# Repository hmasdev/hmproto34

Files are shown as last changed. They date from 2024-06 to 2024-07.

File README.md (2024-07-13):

# hmproto34







hmproto34 is a hand-fitted keyboard with 34 keys.

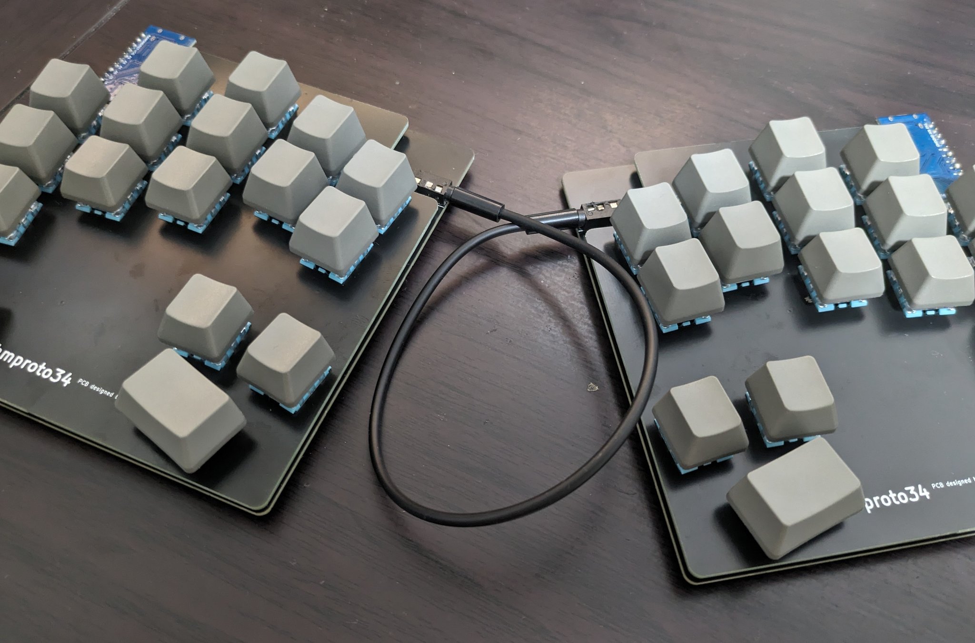
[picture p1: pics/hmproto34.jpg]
hmproto34


## How to Use Firmware

The most simple way to use hmproto34 is to flash the pre-built firmware to your keyboard.

Download the latest firmware from [Releases](https://github.com/hmasdev/hmproto34/releases) and follow the instructions in [How to Flash Firmware](#how-to-flash-firmware).

The next 2 subsections explain how to build firmware and flash it to your keyboard.

If you want to know how to build the keyboard, see [How to Build Keyboard](#how-to-build-keyboard).

### How to Build Firmware

1. Setup your QMK environment
   - if you use Windows, install [QMK MSYS](https://msys.qmk.fm/)
   - See [https://docs.qmk.fm/#/newbs_getting_started?id=set-up-your-environment](https://docs.qmk.fm/#/newbs_getting_started?id=set-up-your-environment) for more information.
   - NOTE: assume that `qmk_firmware` directory is located at `~/qmk_firmware` in the following steps.

2. Open QMK MSYS
   - If you use Windows, open QMK from the start menu. See [https://msys.qmk.fm/guide.html#next-steps](https://msys.qmk.fm/guide.html#next-steps).

3. Clone this repository

   ```sh
   cd ~/qmk_firmware/keyboards
   git clone git@github.com:hmasdev/hmproto34.git
   ```

4. Build firmware

   ```sh
   qmk compile -kb hmproto34 -km default
   ```

Good! Now, you have a built firmware in `~/qmk_firmware/.build/hmproto34_default.hex`.

### How to Flash Firmware

1. Visit [Pro Micro Web Updater](https://sekigon-gonnoc.github.io/promicro-web-updater/index.html);
2. Select the firmware file (`~/qmk_firmware/.build/hmproto34_default.hex`);
3. Connect your left keyboard to your computer and press its reset button;
4. Click the `Flash` button on the website;
5. Wait for the flashing process to complete;
6. Repeat steps 3-5 for the right keyboard.

OK. Now, you can use your hmproto34 keyboard! Try typing something!

## How to Customize Keymap

1. After step 3. of [How to Build Firmware](#how-to-build-firmware), edit `~/qmk_firmware/keyboards/hmproto34/keymaps/default/keymap.c` to customize your keymap. If you want to add a new keymap, run `qmk new-keymap`;

2. Build firmware again;

   ```sh
   qmk compile -kb hmproto34 -km {default or your keymap name}
   ```

3. [Flash firmware again](#how-to-flash-firmware);

## How to Build Keyboard

### Required Components

| Component | Quantity | Note |
| --- | --- | --- |
| PCB | 2 | [Gerber files](./pcb) |
| Top Plate | 2 | [Gerber files](./top_plate) |
| Pro Micro | 2 | |
| TRRS Jack | 2 | |
| TRRS Cable | 1 | 3 or 4 poles |
| Tactile Switch | 2 | Reset Switch |
| Kalih PCB Socket | 34 | For MX Compatible Switch |
| MX Compatible Switch | 34 | |
| KeyCap | 30 (1u), 4 (1u-2u) | |
| Micro USB Cable | 1 | the type of USB depends on the Pro Micro |

### Assembly Steps

1. Solder PCB Sockets to the bottom of PCBs;
2. Attach diodes to the top of PCBs and solder them on the bottom of PCBs;
3. Attach tactile switches and TRRS jacks to the top of PCBs and solder them on the bottom of PCBs;
4. Attach Pro Micros to the top of PCBs;

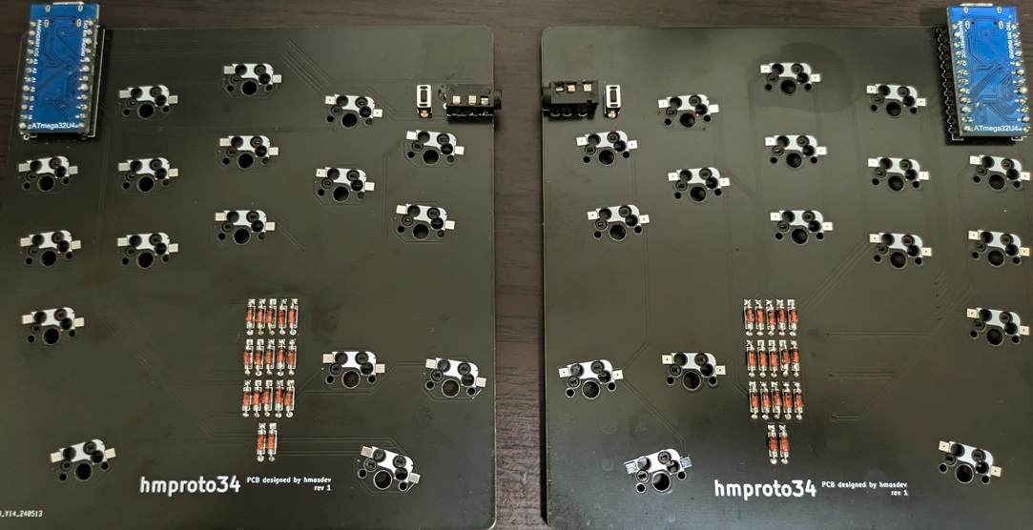
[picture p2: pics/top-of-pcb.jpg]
Top of PCBs
   

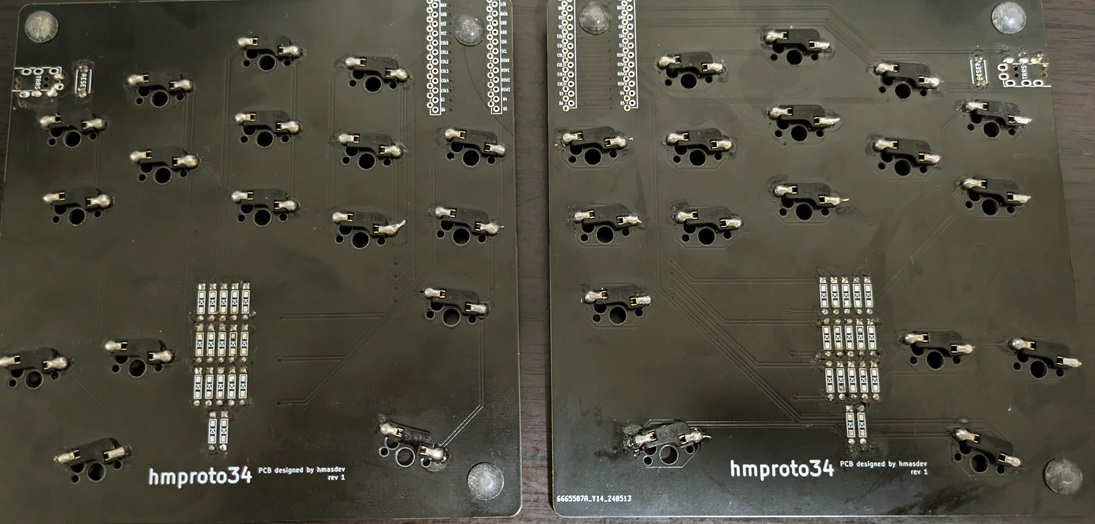
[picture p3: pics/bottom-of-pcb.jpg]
Bottom of PCBs
   

5. Attach key switches to the top plate;

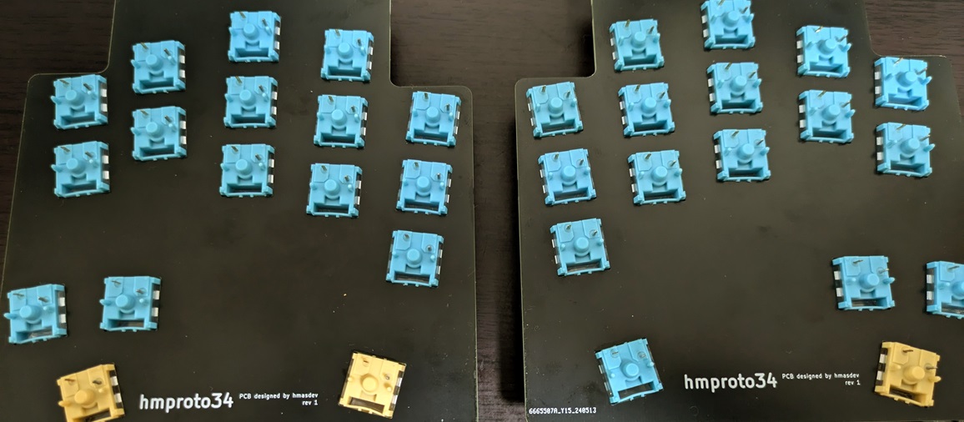
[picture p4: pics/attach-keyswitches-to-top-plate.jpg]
Attach Key Switches to Top Plate
   

6. Joint the top plate and PCBs;
7. Build and flash firmware;
   - See [How to Build Firmware](#how-to-build-firmware) and [How to Flash Firmware](#how-to-flash-firmware) for more information.
8. Connect the left and right keyboards with a TRRS cable;
9. Enjoy typing!

## PCB and Top Plate

### PCB

Gerber files are located in [./pcb](./pcb) directory.
You can order PCBs from PCB manufacturers like JLCPCB etc.

### Top Plate

Gerber files are located in [./top_plate](./top_plate) directory.
You can order PCBs from PCB manufacturers like JLCPCB etc.

See [./top_plate/hmproto34-Edge_Cuts.svg](./top_plate/hmproto34-Edge_Cuts.svg) for the shape of the top plate.

## How to Contribute

1. Fork the repository: [https://github.com/hmasdev/hmproto34](https://github.com/hmasdev/hmproto34)
2. Clone the repository

   ```bash
   git clone https://github.com/{YOURE_NAME}/hmproto34.git
   cd hmproto34
   ```

3. Checkout your working branch

   ```bash
   git checkout -b your-working-branch
   ```

4. Make your changes

5. Commit your changes

   ```bash
   git add .
   git commit -m "Your commit message"
   ```

6. Push your changes

   ```bash
   git push origin your-working-branch
   ```

7. Create a pull request: [https://github.com/hmasdev/hmproto34/compare](https://github.com/hmasdev/hmproto34/compare)

## LICENSE

- [GPLv3](./LICENSE)

## Author

- [hmasdev](https://github.com/hmasdev)

## References

- QMK Firmware: [https://docs.qmk.fm/](https://docs.qmk.fm/#/)
- QMK MSYS: [https://msys.qmk.fm/](https://msys.qmk.fm/)
- kbd:[https://github.com/foostan/kbd](https://github.com/foostan/kbd), [https://github.com/7-rate/kbd](https://github.com/7-rate/kbd)
- Pro Micro Web Updater: [https://sekigon-gonnoc.github.io/promicro-web-updater/index.html](https://sekigon-gonnoc.github.io/promicro-web-updater/index.html)
- 自作キーボード設計入門: [https://pskbd.booth.pm/items/1044084](https://pskbd.booth.pm/items/1044084)

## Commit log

2024-05-23 Add drill and gerber files for top plate and PCB
    [hmproto34-B_Cu.gbr, hmproto34-B_Mask.gbr, hmproto34-B_Paste.gbr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]
2024-06-06 update left bracket combo
2024-06-06 fix device_version in info.json
2024-07-09 feat: Add key combos for reducing index finger load and brackets/quotes
    The code changes introduce new key combos to reduce the load on the index finger and provide shortcuts for typing brackets and quotes. These changes improve the ergonomics and efficiency of the keyboard layout
2025-04-27 fix: update device version to 1.1.0 in info.json
